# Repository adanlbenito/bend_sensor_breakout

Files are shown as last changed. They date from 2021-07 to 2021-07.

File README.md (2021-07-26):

# Bend Sensor Breakout Board for String Instruments

Breakout board Kicad design files for guitar string bend sensors based on [NVE AAT001](https://www.nve.com/angleSensors) Tunnel Magnetoresistive angle sensing technology

The board integrates an AAT001 sensor and an amplifier for both _sine_ and _cosine_ componets and is supposed to be used in conjunction with [N42 neodymium magnets](https://www.first4magnets.com/circular-disc-rod-c34/4mm-dia-x-3mm-thick-n42-neodymium-magnet-0-54kg-pull-p3049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|ps_1_16682). Design files for laser cutting a magnet holder for 3x4mm magnets suitable for an electric guitar with string spacing of 52mm have been included.

## License
These hardware designs are licensed under a [Creative Commons Attribution-Sharealike](https://creativecommons.org/licenses/by-sa/3.0/) license, or [CC-BY-SA](https://creativecommons.org/licenses/by-sa/3.0/).

> Adan L. Benito Temprano and Andrew P. McPherson. _A TMR Angle Sensor for Gesture Acquisition and Disambiguation on the Electric Guitar_. In Proceedings of the International Audio Mostly Conference on Sonic experiences in the era of the Internet of Sounds, September 1-3, 2021, Trento, Italy.
`

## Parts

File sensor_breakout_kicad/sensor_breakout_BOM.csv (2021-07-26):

Id | Designator | Package | Quantity | Designation | Supplier | Ref | Link
1 | C1,C4 | C_0603_1608Metric | 2 | 100nF | Digi-key | 399-14938-2-ND | https://www.digikey.co.uk/product-detail/en/kemet/C0603C101K8RAC7867/399-14938-2-ND/7382054
2 | J3,J1,J2 | JST_PH_S4B-PH-SM4-TB_1x04-1MP_P2.00mm_Horizontal | 3 | Conn_01x04_Female | Digi-key | 455-1751-1-ND | https://www.digikey.co.uk/product-detail/en/jst-sales-america-inc/S4B-PH-SM4-TB-LF-SN/455-1751-1-ND/926848
3 | C2,C3 | C_0603_1608Metric | 2 | 10pF | Digi-key | 399-17686-1-ND | https://www.digikey.co.uk/product-detail/en/kemet/CBR06C100J5GAC/399-17686-1-ND/8572686
4 | R4,R5,R1,R2,R6,R3 | R_0603_1608Metric | 6 | 10M | Digi-key | 2019-UR73D1JTTD10L0FTR-ND | https://www.digikey.co.uk/product-detail/en/koa-speer-electronics-inc/UR73D1JTTD10L0F/2019-UR73D1JTTD10L0FTR-ND/9845673
5 | U2 | TSSOP-8_3x3mm_P0.65mm | 1 | TLV522 | Digi-key | 296-46896-1-ND | https://www.digikey.co.uk/product-detail/en/texas-instruments/TLV522DGKR/296-46896-1-ND/7219538
6 | U1 | TDFN-6-1EP_2.5x2.5mm_P0.65mm_EP1.3x2mm | 1 | AAT001-10E | Digi-key | 391-1065-1-ND | https://www.digikey.co.uk/product-detail/en/nve-corp-sensor-products/AAT001-10E/391-1065-1-ND/3594328

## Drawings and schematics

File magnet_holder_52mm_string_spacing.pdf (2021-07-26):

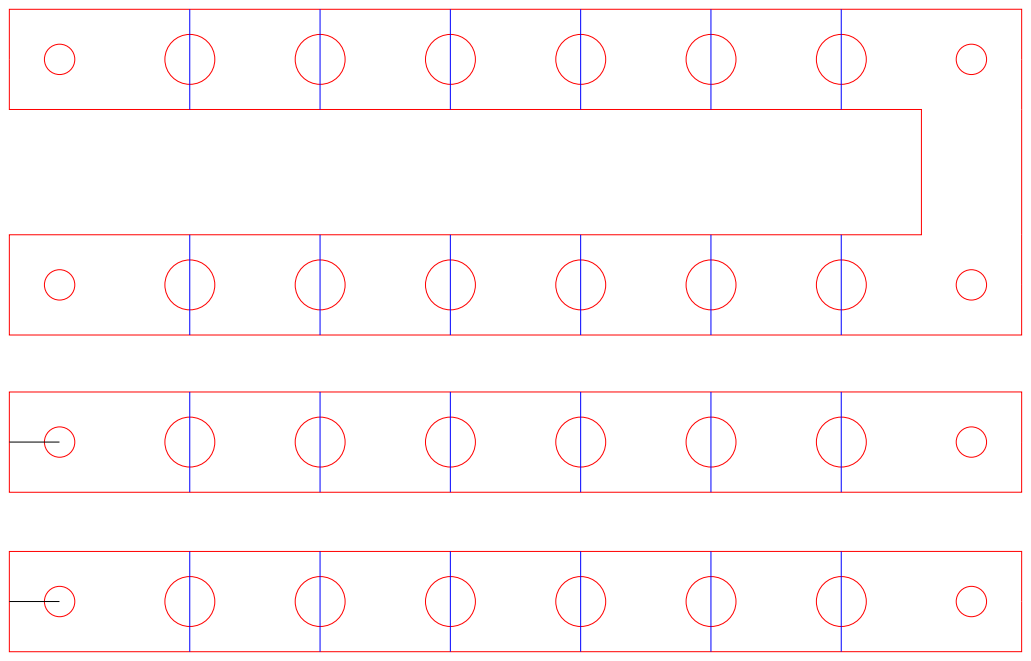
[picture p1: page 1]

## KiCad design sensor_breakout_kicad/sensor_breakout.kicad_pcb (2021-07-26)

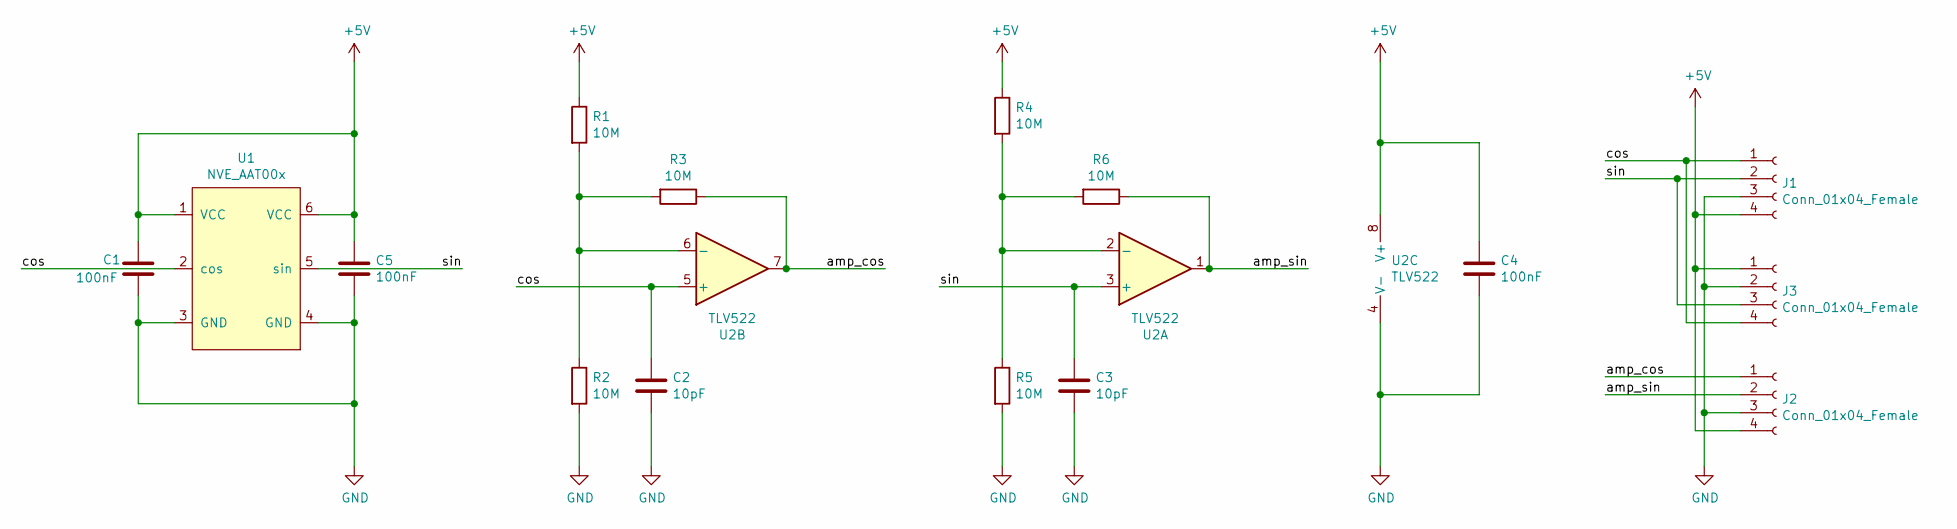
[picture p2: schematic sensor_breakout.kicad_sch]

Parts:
C1, C4, C5: 100nF; C_0603_1608Metric
C2, C3: 10pF; C_0603_1608Metric
J1, J2, J3: Conn_01x04_Female; JST_PH_S4B-PH-SM4-TB_1x04-1MP_P2.00mm_Horizontal
R1, R2, R3, R4, R5, R6: 10M; R_0603_1608Metric
U1: NVE_AAT00x; TDFN-6-1EP_2.5x2.5mm_P0.65mm_EP1.3x2mm_ThermalVias
U2: TLV522; TSSOP-8_3x3mm_P0.65mm

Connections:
+5V: C1.1, C4.1, C5.1, J1.4, J2.4, J3.1, R1.1, R4.1, U1.1 (VCC), U1.6 (VCC), U2.8 (V+)
/amp_cos: J2.1, R3.1, U2.7
/amp_sin: J2.2, R6.1, U2.1
/cos: C2.1, J1.1, J3.4, U1.2 (cos), U2.5 (+)
/sin: C3.1, J1.2, J3.3, U1.5 (sin), U2.3 (+)
GND: C1.2, C2.2, C3.2, C4.2, C5.2, J1.3, J2.3, J3.2, R2.2, R5.2, U1.3 (GND), U1.4 (GND), U2.4 (V-)
unnamed: R1.2, R2.1, R3.2, U2.6 (-)
unnamed: R4.2, R5.1, R6.2, U2.2 (-)

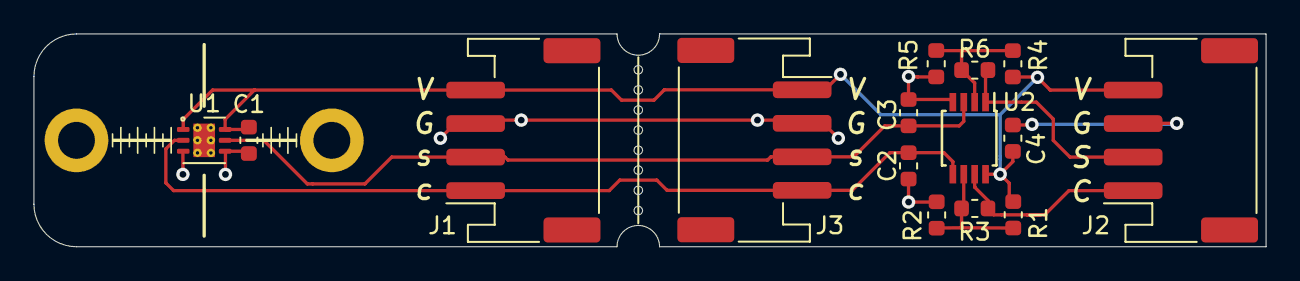
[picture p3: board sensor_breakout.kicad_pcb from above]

Board: 2 copper layers, 73.5 x 12.7 mm, 15 parts (0 on the bottom side), 8 nets.

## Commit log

2021-07-26 Added Kicad files
    [sensor_breakout.kicad_pcb, sensor_breakout.kicad_sch, sensor_breakout_BOM.csv]
2021-07-26 Added magnet holder laser cutting files
